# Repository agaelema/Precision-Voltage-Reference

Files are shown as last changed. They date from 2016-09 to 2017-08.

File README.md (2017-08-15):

# Precision Voltage Reference

A simple and efficient instrumentation project of a Precision Voltage Reference. The idea of this project appeared with my passion by the instrumentation and my need of some reference to calibrate my projects involving energy measurement. 

Searching for similar projects I encountered some videos from the Youtube channel "Scullcom Hobby Electronics". This two videos was the kick for my project.
- [Video 1](https://youtu.be/QnH5O-AhqAU?list=PLqnWlo4M8pvoofVfDM7LorucKpwpznr12)
- [Video 2](https://youtu.be/QnH5O-AhqAU?list=PLqnWlo4M8pvoofVfDM7LorucKpwpznr12)

The project is based in the [TI REF102](http://www.ti.com/product/REF102), an 10 V precision voltage reference with maximum tolerance of 0,025% (0.0025 V) in the better model.

Other 4 outputs are derived from the 10 V output, making available 10 V, 5V, 2,50V, 1,125 V and 0,625 V.  This values are obtained using the Precision Difference Amplifier [INA2133](http://www.ti.com/product/INA2133)

The original idea is to be a simple project with components easily found in the market.

### The Supply

The project is powered by a common 5V power bank, and the output of the power bank is applied to a DC/DC step up to 20 V. With one LM317 and one LM337 we generates the positive supply for the REF102 and negative voltage to compensate some offset in the INAs.

The output is referenced to a Virtual ground, not the GND from the power bank.

Linear power supply

### The Outputs

Using the INA2133 is possible to implement a 1/2 divider with great precision. At the same time the outputs are buffered between the stages.

To compensate some possible input offset in the stages, was implements simple circuits to externally compensate the offset. This circuit inject some voltage in the Ref pin of the INA.

The ideia of divider:
INA 1/2 Divider

### The Result

The project was developed using Kicad. The [complet schematic](https://github.com/agaelema/Precision-Voltage-Reference/blob/master/ref-schematic-big.png) is presented bellow.

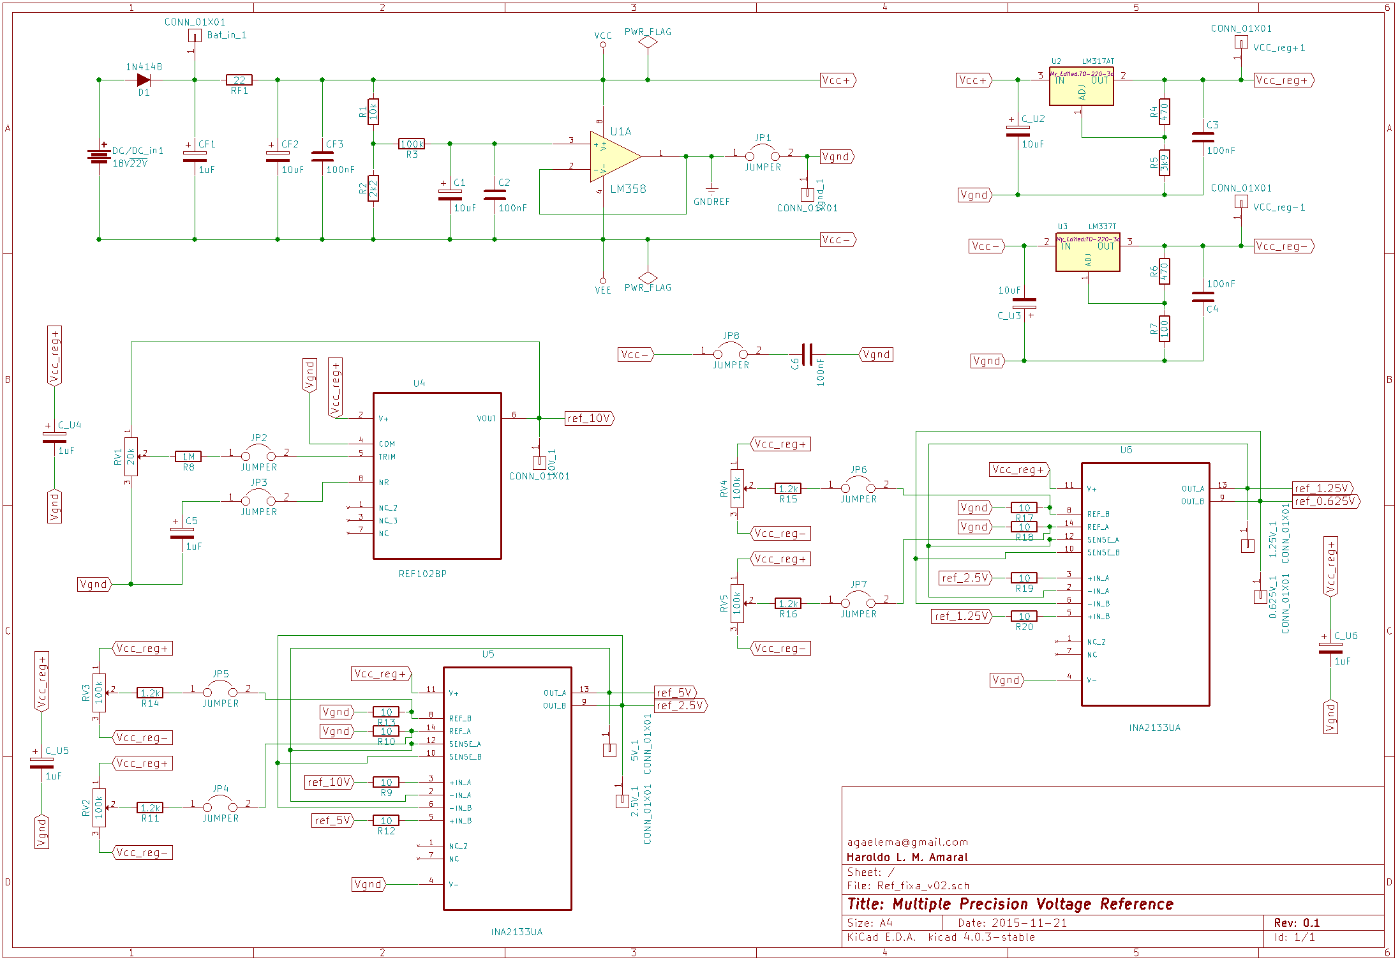
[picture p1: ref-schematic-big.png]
Schematic


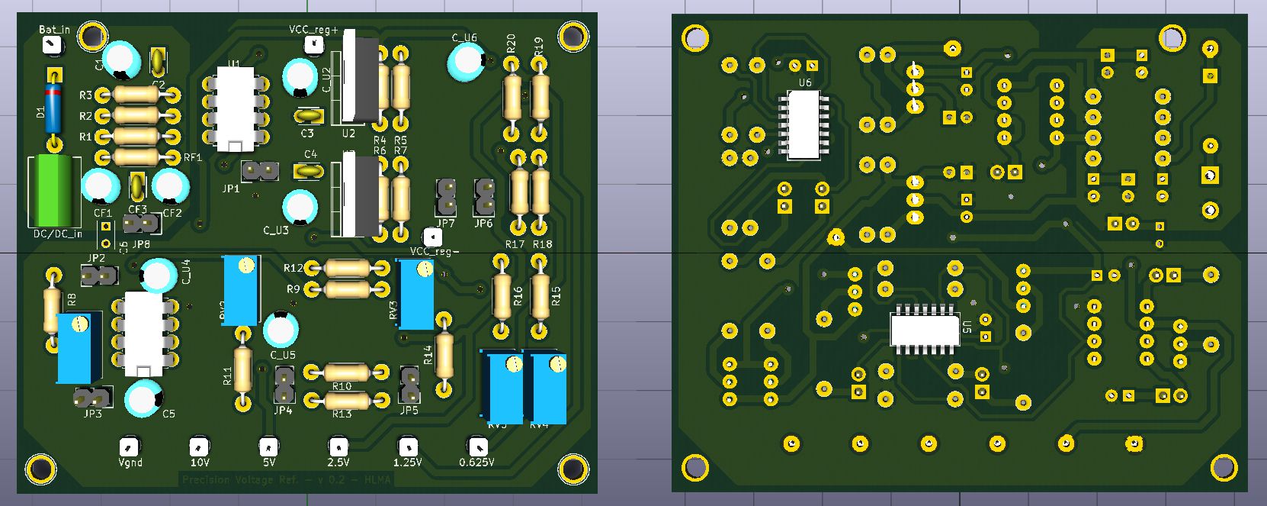
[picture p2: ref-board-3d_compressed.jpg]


The assembled board.

Assembled board

The results without calibration (default value), calibrating just the REF102 output and calibrating each output individually.

Assembled board

### Related Articles

There is a serie of 4 articles talking about this project.
- [Article 1 (The idea)](https://www.embarcados.com.br/referencia-de-tensao-de-precisao-a-ideia/)
- [Article 2 (The power supply)](https://www.embarcados.com.br/desenvolvendo-a-fonte-para-referencia-de-precisao/)
- [Article 3 (The voltage reference)](https://www.embarcados.com.br/referencia-de-tensao-da-referencia-de-precisao/)
- [Article 4 (The results)](https://www.embarcados.com.br/resultados-referencia-de-precisao/)

### DISCLAIMER

This project is provided 'as is' with no explicit or implied warranties in respect of its properties, including, but not limited to, correctness and/or fitness for purpose.

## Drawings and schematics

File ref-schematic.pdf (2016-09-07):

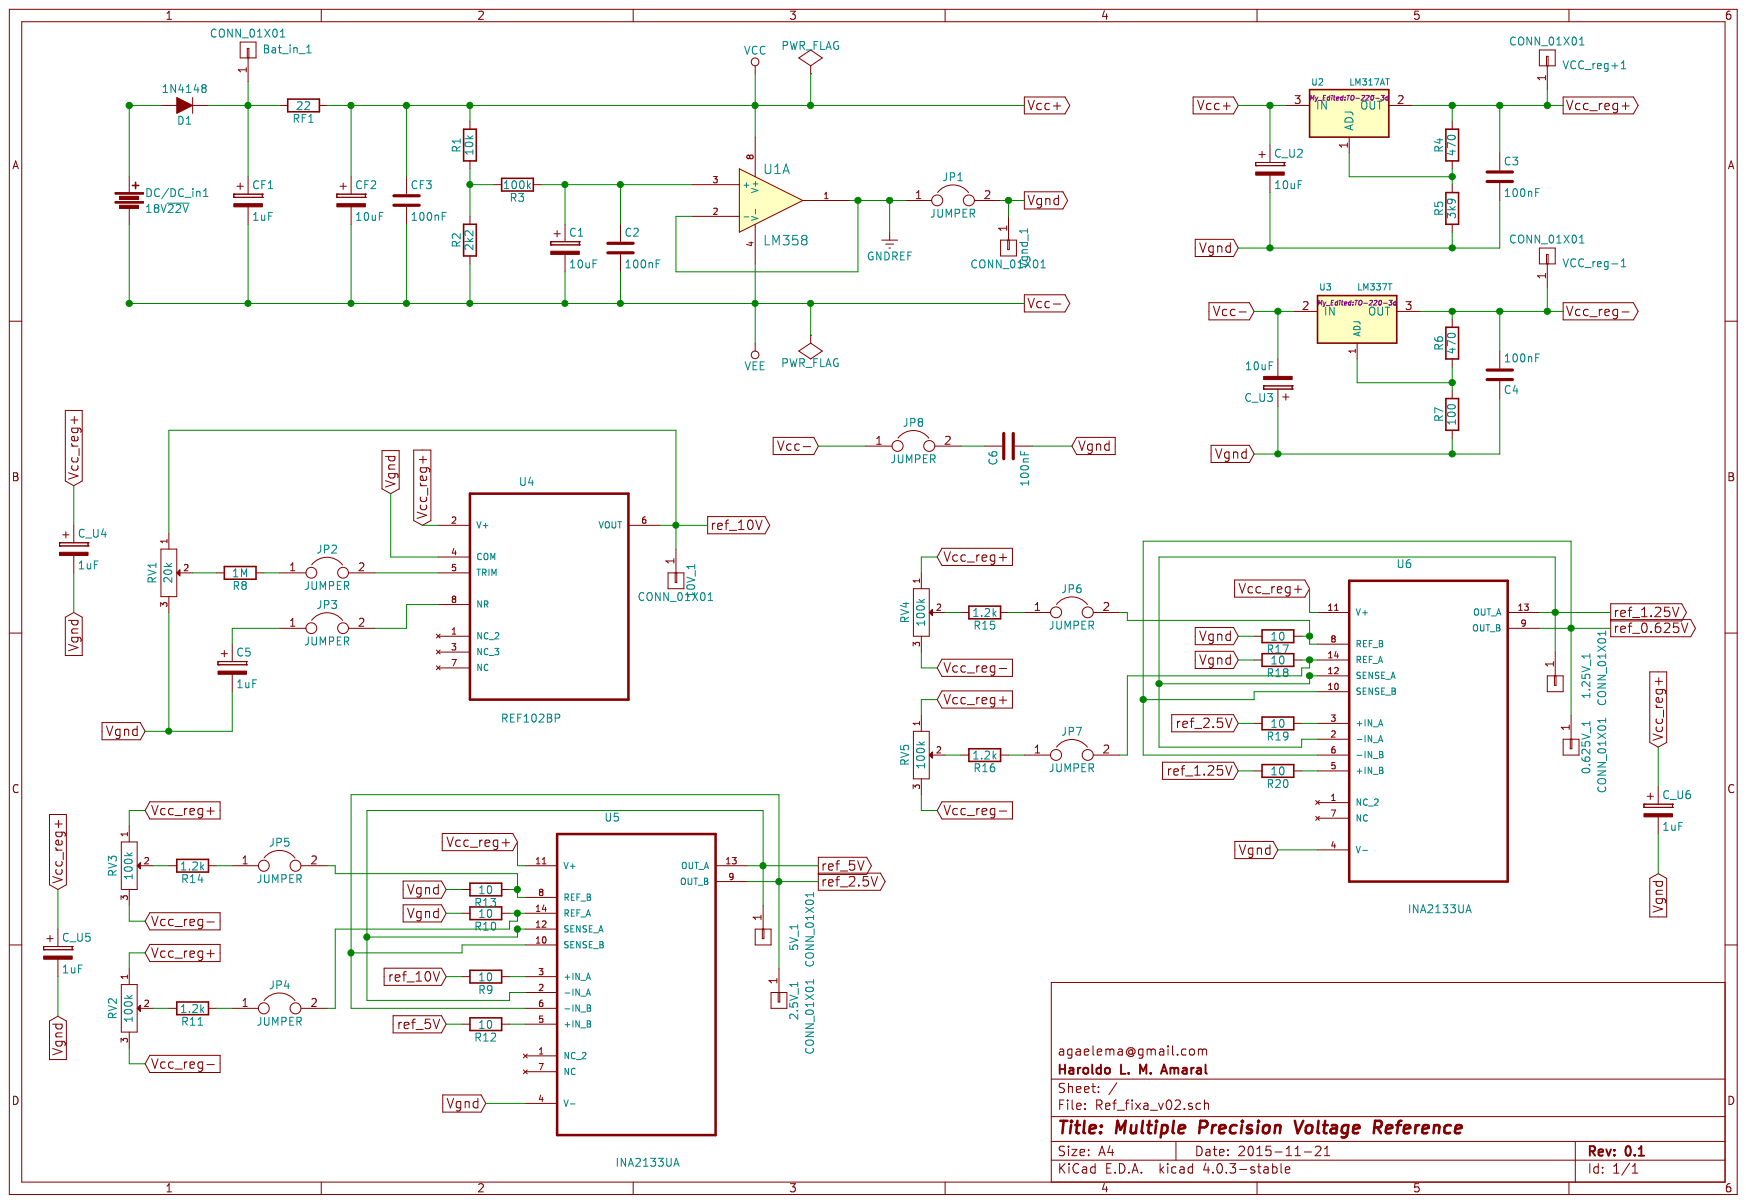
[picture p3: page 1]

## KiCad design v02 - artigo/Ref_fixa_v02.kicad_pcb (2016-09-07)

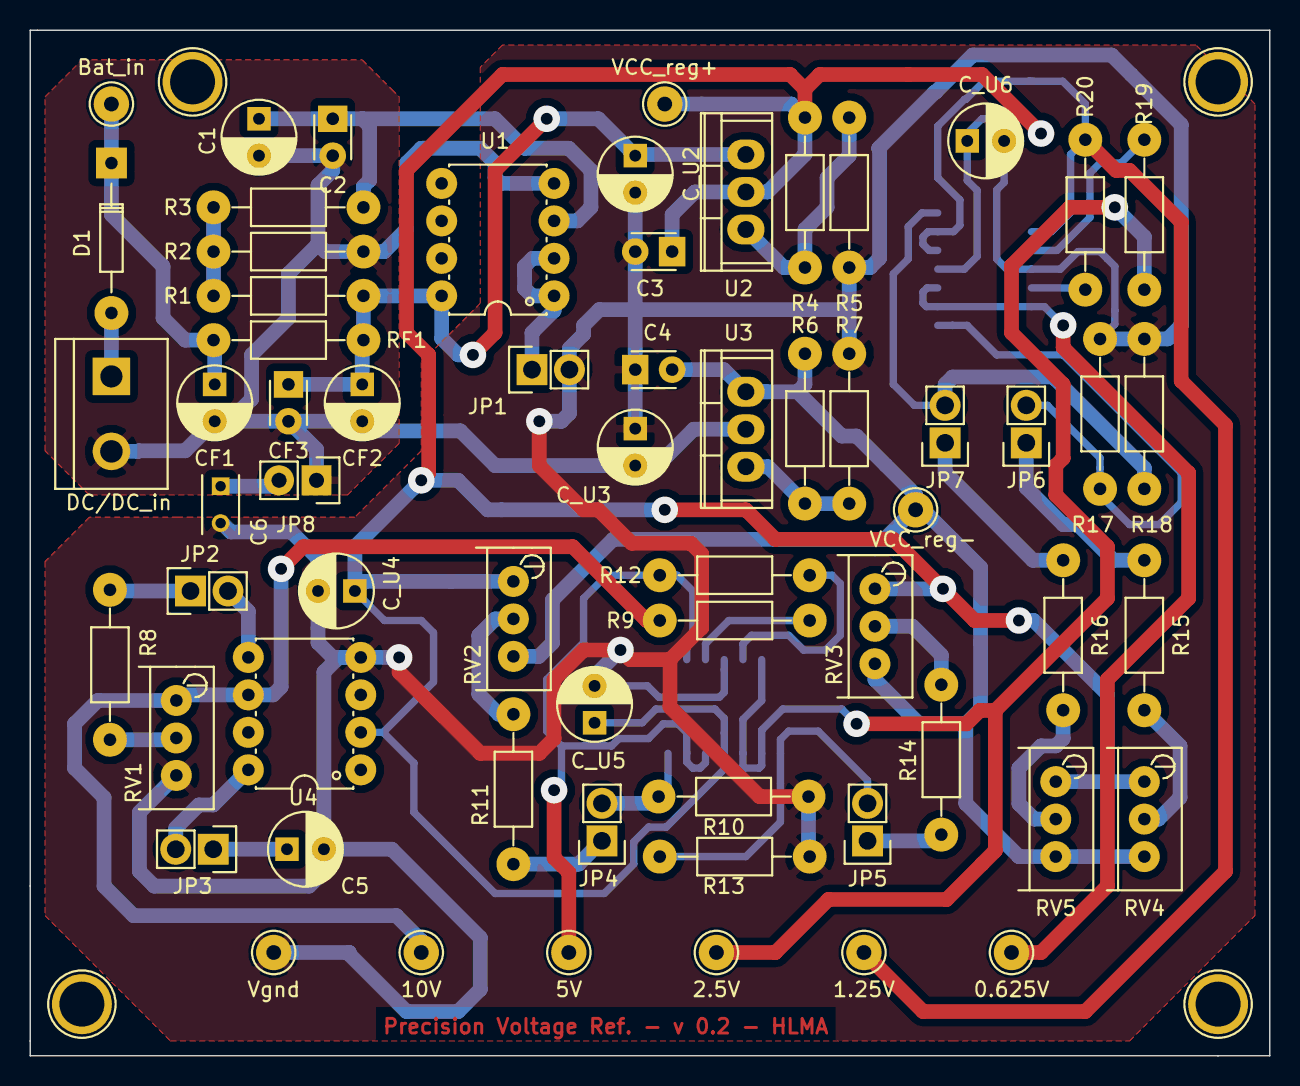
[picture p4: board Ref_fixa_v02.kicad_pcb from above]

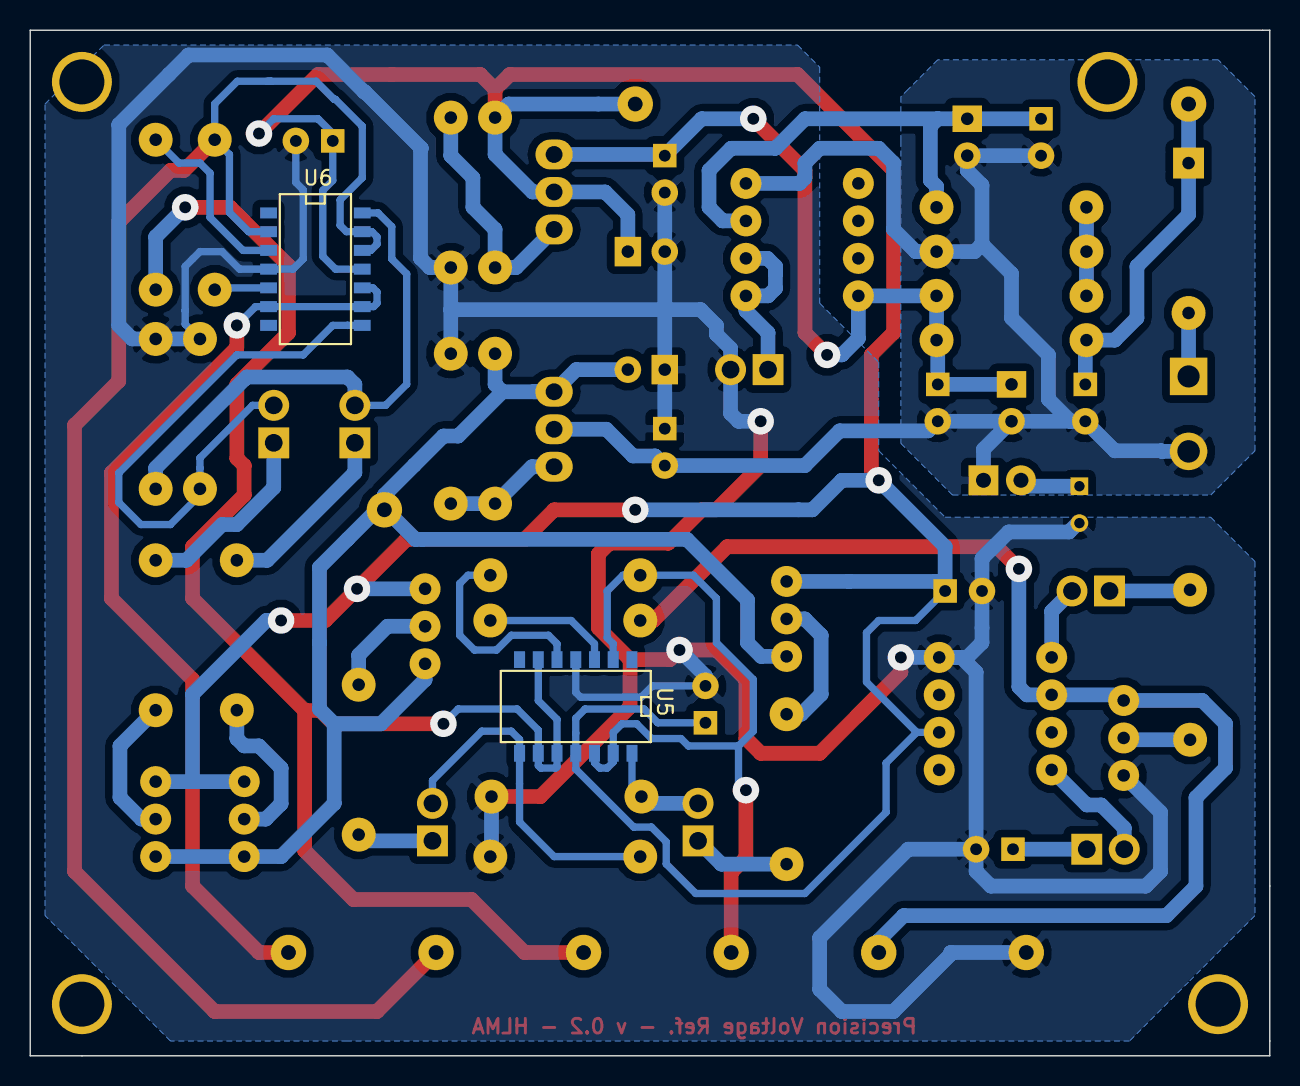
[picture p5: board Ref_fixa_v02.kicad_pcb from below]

Board: 2 copper layers, 84.0 x 69.5 mm, 65 parts (2 on the bottom side), 39 nets.

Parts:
0.625V, 1.25V, 2.5V, 5V, 10V: CONN_01X01; PINTST-2.4-1.0mm
Bat_in: CONN_01X01; PINTST-2.4-1.0mm
C1: 10uF; C_Radial_D5_L6_P2.5-1.6mm
C2, C3, C4: 100nF; C_Disc_D3_P2.5-1.8-0.85mm
C5: 1uF; C_Radial_D5_L6_P2.5-1.6mm
C6: 100nF; C_Rect_L4_W2.5_P2.5
CF1: 1uF; C_Radial_D5_L6_P2.5-1.6mm
CF2: 10uF; C_Radial_D5_L6_P2.5-1.6mm
CF3: 100nF; C_Disc_D3_P2.5-1.8-0.85mm
C_U2, C_U3: 10uF; C_Radial_D5_L6_P2.5-1.6mm
C_U4, C_U5, C_U6: 1uF; C_Radial_D5_L6_P2.5-1.6mm
D1: 1N4148; Diode_DO-35_SOD27_Horizontal_RM10-2.1mm
DC/DC_in: 18V-22V; bornier2-edit
JP1, JP2, JP3, JP4, JP5, JP6, JP7: JUMPER; Pin_Header_Straight_1x02-2,1-1,2mm
JP8: JUMPER; Pin_Header_Straight_1x02
R1: 10k; Resistor_Horizontal_RM10mm-2.3-0.85mm
R2: 2k2; Resistor_Horizontal_RM10mm-2.3-0.85mm
R3: 100k; Resistor_Horizontal_RM10mm-2.3-0.85mm
R4, R6: 470; Resistor_Horizontal_RM10mm-2.3-0.85mm
R5: 3k9; Resistor_Horizontal_RM10mm-2.3-0.85mm
R7: 100; Resistor_Horizontal_RM10mm-2.3-0.85mm
R8: 1M; Resistor_Horizontal_RM10mm-2.3-0.85mm
R9, R10, R12, R13, R17, R18, R19, R20: 10; Resistor_Horizontal_RM10mm-2.3-0.85mm
R11, R14, R15, R16: 1.2k; Resistor_Horizontal_RM10mm-2.3-0.85mm
RF1: 22; Resistor_Horizontal_RM10mm-2.3-0.85mm
RV1: 20k; Potentiometer-pinlinear-2.1-0.85mm
RV2, RV3, RV4, RV5: 100k; Potentiometer-pinlinear-2.1-0.85mm
U1: LM358; PDIP-8-3d-2.1-0.85mm
U2: LM317AT; TO-220-3d
U3: LM337T; TO-220-3d
U4: REF102BP; PDIP-8-3d-2.1-0.85mm
U5, U6: INA2133UA; SOIC-14_N-0.75mm
VCC_reg+: CONN_01X01; PINTST-2.4-1.0mm
VCC_reg-: CONN_01X01; PINTST-2.4-1.0mm
Vgnd: CONN_01X01; PINTST-2.4-1.0mm

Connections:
GNDREF: JP1.1, U1.1, U1.2
unnamed: Bat_in.1, CF1.1, D1.1, RF1.2
unnamed: C1.1, C2.1, R3.1, U1.3
unnamed: C5.1, JP3.1
unnamed: C6.1, JP8.2
unnamed: D1.2, DC/DC_in.1
unnamed: JP2.1, R8.1
unnamed: JP2.2, U4.5
unnamed: JP3.2, U4.8
unnamed: JP4.1, R11.1
unnamed: JP4.2, R10.1, U5.14
unnamed: JP5.1, R14.1
unnamed: JP5.2, R13.1, U5.8
unnamed: JP6.1, R15.1
unnamed: JP6.2, R17.1, U6.8
unnamed: JP7.1, R16.1
unnamed: JP7.2, R18.1, U6.14
unnamed: R1.1, R2.2, R3.2
unnamed: R4.1, R5.2, U2.1
unnamed: R6.2, R7.1, U3.1
unnamed: R8.2, RV1.2
unnamed: R9.1, U5.3
unnamed: R11.2, RV2.2
unnamed: R12.1, U5.5
unnamed: R14.2, RV3.2
unnamed: R15.2, RV4.2
unnamed: R16.2, RV5.2
unnamed: R19.1, U6.3
unnamed: R20.1, U6.5
Vcc+: CF2.1, CF3.1, C_U2.1, R1.2, RF1.1, U1.8, U2.3
Vcc-: C1.2, C2.2, CF1.2, CF2.2, CF3.2, C_U3.2, DC/DC_in.2, JP8.1, R2.1, U1.4, U3.2
Vcc_reg+: C3.1, C_U4.1, C_U5.1, C_U6.1, R4.2, RV2.1, RV3.1, RV4.1, RV5.1, U2.2, U4.2, U5.11, U6.11, VCC_reg+.1
Vcc_reg-: C4.2, R6.1, RV2.3, RV3.3, RV4.3, RV5.3, U3.3, VCC_reg-.1
Vgnd: C3.2, C4.1, C5.2, C6.2, C_U2.2, C_U3.1, C_U4.2, C_U5.2, C_U6.2, JP1.2, R5.1, R7.2, R10.2, R13.2, R17.2, R18.2, RV1.3, U4.4, U5.4, U6.4, Vgnd.1
ref_0.625V: 0.625V.1, U6.6, U6.9, U6.10
ref_1.25V: 1.25V.1, R20.2, U6.2, U6.12, U6.13
ref_2.5V: 2.5V.1, R19.2, U5.6, U5.9, U5.10
ref_5V: 5V.1, R12.2, U5.2, U5.12, U5.13
ref_10V: 10V.1, R9.2, RV1.1, U4.6
